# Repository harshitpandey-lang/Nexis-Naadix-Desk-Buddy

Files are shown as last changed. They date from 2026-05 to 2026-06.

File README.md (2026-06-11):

# Nexis
model_nexis_2026-Jun-03_01-21-36AM-000_CustomizedView11682904690_png

Nexis is a dual AI powered desk automation bot which uses raspberry pi to run a local llm and also uses a cloud deployed ai agent to do the tasks given to it in small chunks. We can give instructions through the interactive touch screen and also through the micophone. 
It uses esp32 to give commands to the device connected through the USB. 

## Overview

Nexis is a desk buddy which can do all sort of works upon good training and customisation. It uses a raspberry pi and open source AI model to break works into smaller steps. It uses the the local llm to generte the HID code respective to every step given uses python to asses if the work is performed then goes ahed with next step till all are completed. 
It uses esp32 to give HID code to the PC connected to make it do or perform a particular task. It can communicate or given instructionthrough the Touchscreen and Microphone.

---

## System Architecture
User

 │
 
 ├── Voice Input
 
 ├── Touchscreen Input
 
 │
 
 ▼
 
Raspberry Pi 4

 │
 
 ├── Local LLM
 
 ├── Task Planner
 
 ├── Verification Engine
 
 └── Cloud AI Agent
 
 │
 
 ▼
 
ESP32-S3 HID Controller

 │
 
 ▼
 
Connected Computer

 │
 
 ├── Keyboard Events
 
 ├── Mouse Events
 
 └── Workflow Execution

## Specifications

| Parameters | Value |
| Code | Python|
| Hardware | Raspberry pi model B |
| Design | 3d printed and rubber keys|

### Hardware

| Component | Purpose |
|---|---|
| Raspberry Pi 4 Model B | Main computing unit |
| Official Raspberry Pi Display | User interface |
| ESP32-S3 | HID controller |
| INMP441 Microphone | Voice input |
| MAX98357A Amplifier | Audio output |
| Speaker | Voice feedback |
| Rotary Encoder | Navigation control |
| Push Buttons | User interaction |
| LiPo Battery | Portable power |

{549CDC2C-EC70-4538-B992-6CFFC3E95AC3}
nexus deskbuddy

See BOM.md for the complete bill of materials.

---

## Software

- Backend Language
  - Python
- Framework
  - FastAPI
- AI
  - OpenAI API
  - Claude API
  - Gemini API
- Data Models
  - Pydantic
- Hosting
  - Render

### Raspberry Pi

Install:

* Raspberry Pi OS
* Python
* Git
* Required libraries

### ESP32

Install:

* Arduino IDE or PlatformIO
* ESP32 Board Package

---

### How It Works
- User gives an instruction.
- Nexis interprets the request.
- AI breaks the task into smaller steps.
- Local verification checks progress.
- ESP32 receives generated HID commands.
- Commands are executed on the connected computer.
- Nexis confirms completion and proceeds to the next step.

This process continues until the entire workflow is completed.

---

## Gallery

<p align="center">
  
  
  
</p>

<p align="center">
  
  
  
</p>

## Future Improvements

- It can work as full work automation
- It can also control the other tech stacks of your rooms
- If developed correctly it can do the job of any person

## Acknowledgement

- The raspberrry pi model 4 was alloted by my college (Jaypee Institute of Information Technology), which I am grateful.
- I am grateful for the oppurtunity presented by the Hack Club called fallout, Which I am a part of and am proud of making this project under their guidance for more reference realted to the fallout event (https://fallout.hackclub.com/path).
- I am also grateful for the help given by my seniors.

---
# Zine page
WhatsApp Image 2026-06-04 at 8 46 59 AM

---

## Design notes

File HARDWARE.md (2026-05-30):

# Hardware Documentation

## Overview

Nexis is a desktop companion designed around a Raspberry Pi and an ESP32-S3. The Raspberry Pi acts as the primary controller while the ESP32-S3 provides USB HID functionality for interacting with a computer.

The hardware was designed to provide:

* Voice input
* Audio output
* Touchscreen interaction
* Physical controls
* USB HID automation
* Portable power support

---

# System Architecture

```text
                 User
                   │
                   ▼
         Official Pi Display
                   │
                   ▼
             Raspberry Pi
        ┌──────────┼──────────┐
        │          │          │
        ▼          ▼          ▼
    Microphone  Speaker    ESP32-S3
        │                     │
        ▼                     ▼
    Voice Input         USB HID Output
                              │
                              ▼
                           Computer
```

---

# Main Controller

## Raspberry Pi

Role:

* System controller
* User interface
* Voice processing
* OAI communication
* Feedback monitoring

Connected Components:

* Display
* Microphone
* Amplifier
* ESP32 Interface
* Buttons
* Rotary Encoder

---

# HID Controller

## ESP32-S3

Role:

* Keyboard emulation
* Mouse emulation
* Command execution
* Secondary communication controller

Benefits:

* Native USB support
* WiFi support
* Low power consumption
* Reliable HID operation

---

# Display

## Official Raspberry Pi Touchscreen

Purpose:

* Device status
* User interaction
* Task approval
* Settings menu

Displayed Information:

* Network status
* Voice status
* Current task
* Approval prompts
* Error messages

---

# Audio Input

## INMP441 I2S Microphone

Purpose:

* Voice command capture

Interface:

* I2S

Connections:

```text
3V3
GND
WS
SCK
SD
```

Connected To:

* Raspberry Pi

---

# Audio Output

## MAX98357A Amplifier

Purpose:

* Audio playback
* Voice feedback

Interface:

* I2S

Connected To:

* Raspberry Pi

Output:

* 3W Speaker

---

# Rotary Encoder

Purpose:

* Navigation
* Volume control
* Menu selection

Signals:

```text
CLK
DT
SW
```

Connected To:

* Raspberry Pi GPIO

---

# Front Panel Buttons

Purpose:

* Manual control
* Emergency stop
* Menu navigation

Functions:

* Confirm
* Cancel
* Back
* Wake Device

---

# Power System

## USB-C Input

Primary power source.

Provides:

* Raspberry Pi power
* Peripheral power
* Charging input

---

## Battery Support

Optional portable operation.

Supports:

* Single-cell LiPo battery

Functions:

* Backup power
* Portable usage

---

# Speaker

Purpose:

* Audio feedback
* Notifications
* Voice responses

Connected Through:

```text
MAX98357A
        ↓
      Speaker
```

---

# Internal Communication

## Raspberry Pi ↔ ESP32-S3

Purpose:

* Command transfer
* Status reporting

Possible Interfaces:

* UART
* MQTT over WiFi
* USB Serial

Current Design:

* MQTT communication

---

# Hardware Features

### Input

* Touchscreen
* Microphone
* Buttons
* Rotary Encoder

### Output

* Speaker
* Display
* HID Keyboard
* HID Mouse

### Connectivity

* WiFi
* USB

### Power

* USB-C
* Battery Backup

---

# Design Goals

1. Simple architecture

2. Reliable HID operation

3. Easy assembly

4. Expandable design

5. Portable operation

6. Educational value

7. Hack Club Fallout compatibility

---

# Revision

Current Revision: V1

Status:

* Schematic Complete
* PCB In Development
* Firmware In Development
* Assembly Pending

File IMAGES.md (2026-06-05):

# 📸 Nexis Project Gallery

<table>
<tr>
<td width="50%">

</td>

<td width="50%">

</td>
</tr>
</table>

---

<table>
<tr>
<td width="33%">

</td>

<td width="33%">

</td>

<td width="33%">

</td>
</tr>

<tr>
<td width="33%">

</td>

<td width="33%">

</td>

<td width="33%">

</td>
</tr>
</table>

---

## 🛠️ Design Process

<table>
<tr>
<td></td>
<td></td>
<td></td>
</tr>

<tr>
<td></td>
<td></td>
<td></td>
</tr>

<tr>
<td></td>
<td></td>
<td></td>
</tr>

<tr>
<td></td>
<td></td>
<td></td>
</tr>

<tr>
<td></td>
<td></td>
<td></td>
</tr>

<tr>
<td></td>
<td></td>
<td></td>
</tr>

<tr>
<td></td>
<td></td>
<td></td>
</tr>

<tr>
<td></td>
<td></td>
<td></td>
</tr>

<tr>
<td colspan="3">

</td>
</tr>
</table>

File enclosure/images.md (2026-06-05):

## Interactive CAD Models

<p align="center">
  <a href="https://autode.sk/49pJZgw">
    
  </a>

  <a href="https://autode.sk/3PAl5UJ">
    
  </a>
</p>

---

## Final Design Renders

<p align="center">
  
  
  
</p>

<p align="center">
  
  
</p>

---

## Design & Development Process

<p align="center">
  
  
  
</p>

<p align="center">
  
  
  
</p>

<p align="center">
  
  
  
</p>

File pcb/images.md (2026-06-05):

## 🚀 Interactive CAD Models

<p align="center">
  <a href="https://autode.sk/49pJZgw">
    
  </a>

  <a href="https://autode.sk/3PAl5UJ">
    
  </a>
</p>

<p align="center">
  <a href="https://autode.sk/49pJZgw">
    
  </a>
</p>

<p align="center">
Click the preview above to explore the interactive Fusion 360 model.
</p>

---

## 📸 CAD Design Gallery

<table>
<tr>
<td></td>
<td></td>
</tr>

<tr>
<td></td>
<td></td>
</tr>

<tr>
<td></td>
<td></td>
</tr>

<tr>
<td></td>
<td></td>
</tr>

<tr>
<td></td>
<td></td>
</tr>
</table>
 src="https://github.com/user-attachments/assets/829b629e-79f1-4ea2-8aa1-b12885084f9d" />
Screenshot (43)

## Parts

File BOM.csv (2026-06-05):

Item | Category | Qty | Unit Price (INR) | Total (INR) | Supplier | Product Link | Purpose | Notes
Raspberry Pi 4 Model B (4GB) | Compute | 1 | 11299 | 11299 | Robu | https://robu.in/product/raspberry-pi-4-model-b-with-4-gb-ram/ | Main Controller | Runs UI voice processing and OAI communication
Seeed Studio 7 inch Capacitive Touchscreen | Display | 1 | 10139 | 10139 | Robu | https://robu.in/product/seeed-studio-7-inch-1024x600-capacitive-touchscreen/ | Primary User Interface | 1024x600 touchscreen display
ESP32-S3 N16R8 Development Board | Microcontroller | 1 | 540 | 540 | Robu | https://robu.in/product/esp32-s3-development-board-with-s3-n16r8/ | USB HID Controller | Keyboard and mouse emulation
GY-SPH0645LM4H I2S MEMS Microphone | Audio Input | 1 | 489 | 489 | Robu | https://robu.in/product/gy-sph0645lm4h-i2s-digital-audio-interfaces-mems-microphone-sensor/ | Voice Capture | I2S digital microphone
Adafruit MAX98357A I2S Amplifier | Audio Output | 1 | 730 | 730 | Robu | https://robu.in/product/adafruit-max98357a-i2s-3w-class-d-amplifier-breakout-board/ | Speaker Amplifier | Digital audio amplifier
Electronic Spices 2in 4Ω 5W Speaker | Audio Output | 1 | 143 | 143 | Amazon | https://www.amazon.in/Electronic-Spices-Power-Woofer-Speaker/dp/B0BN44HPF9/ | Voice Feedback | Main speaker
KY-040 Rotary Encoder Module | Input | 1 | 107 | 107 | Amazon | https://www.amazon.in/Electronic-Spices-KY-040-encoder-development/dp/B0BHWCWJDR/ | Navigation Control | Menu and volume navigation
Tactile Push Buttons | Input | 3 | 19 | 57 | Amazon | https://www.amazon.in/Tactile-momentry-button-Switch-Button/dp/B07NCZJX3M/ | User Controls | Confirm cancel shortcut buttons
Samsung INR50S 5000mAh Battery | Power | 1 | 649 | 649 | Robu | https://robu.in/product/samsung-3-7v-5000mah-drone-battery-pack/ | Portable Power | Optional battery backup
2 Pin Male Female Wire Connector Set | Power | 1 | 88 | 88 | Amazon | https://www.amazon.in/Female-2-5mm-Cable-Connector-Silicone/dp/B0837W4DC8/ | Battery and Internal Wiring Connector | Pre-wired male and female connectors for battery and module connections
USB-C Connector Module | Power | 1 | 50 | 50 | Generic | Local Supplier | Power Input | USB-C charging and power
Fan Header 2 Pin | Expansion | 1 | 15 | 15 | Generic | Local Supplier | Cooling Expansion | Future cooling support
2.54mm Pin Headers | Connectors | 2 | 20 | 40 | Generic | Local Supplier | Interconnects | GPIO breakout connections
PCB Fabrication (2 Layer) | PCB | 1 | 1200 | 1200 | JLCPCB | https://jlcpcb.com/ | Custom PCB | Main Nexis PCB
PCB Assembly Components Set | PCB | 1 | 500 | 500 | Mouser/DigiKey | Various | Passives | Resistors capacitors LEDs connectors
M2.5 Standoffs and Screws | Mechanical | 1 | 200 | 200 | Amazon | Various | Assembly | PCB and display mounting
Internal Wiring Set | Mechanical | 1 | 250 | 250 | Amazon | Various | Wiring | Jumper wires JST cables
3D Printed Enclosure | Mechanical | 1 | 1500 | 1500 | Self Manufactured | N/A | Enclosure | Fusion 360 custom design
USB-C Cable | Accessory | 1 | 150 | 150 | Amazon | Various | Power and Debugging | Development and deployment
Miscellaneous Hardware | Mechanical | 1 | 300 | 300 | Various | Various | Assembly | Adhesive spacers nuts inserts

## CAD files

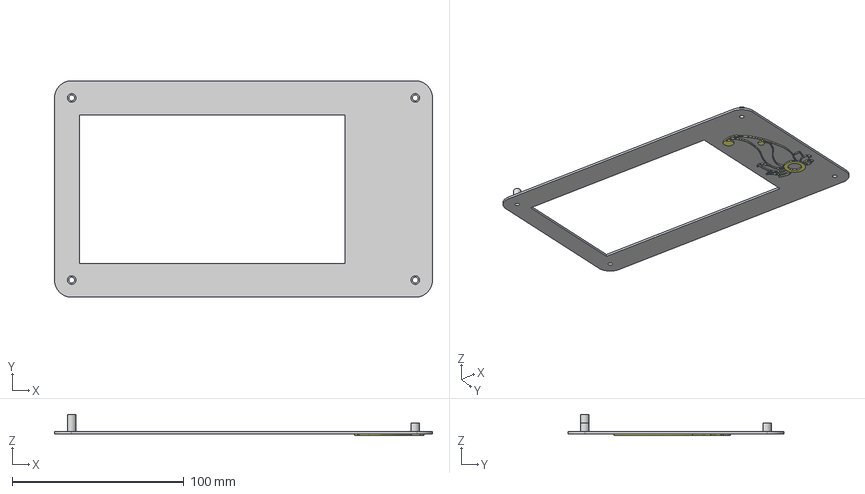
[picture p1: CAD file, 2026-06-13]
enclosure/Nexus desk front.step
220.0 x 126.0 x 12.5 mm

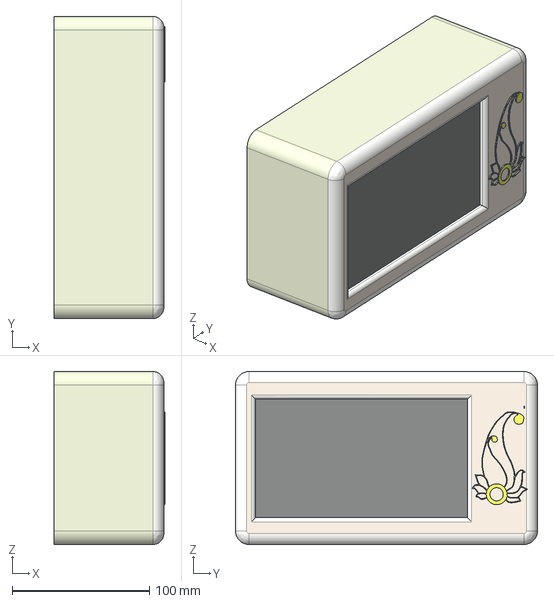
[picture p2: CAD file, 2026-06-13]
enclosure/model nexis.step
80.8 x 220.0 x 126.0 mm

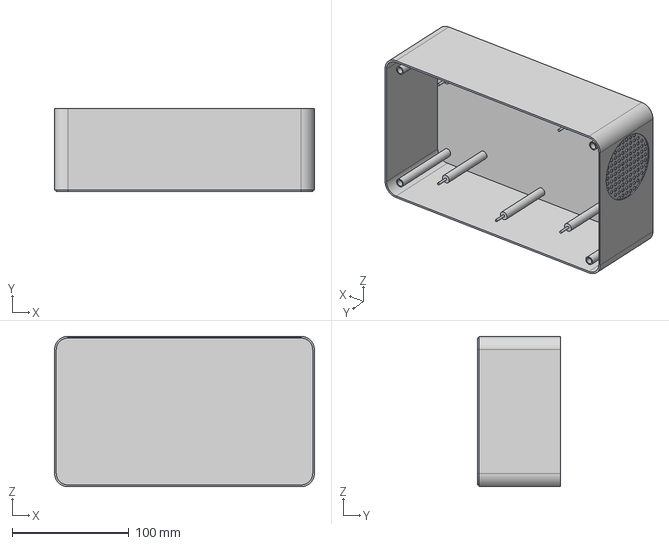
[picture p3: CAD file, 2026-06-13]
enclosure/nexus back.step
223.0 x 71.5 x 129.0 mm

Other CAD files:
enclosure/Nexus desk front.3mf
enclosure/Nexus desk front.f3d
enclosure/model nexis.3mf
enclosure/model nexis.f3z
enclosure/nexus back.f3d

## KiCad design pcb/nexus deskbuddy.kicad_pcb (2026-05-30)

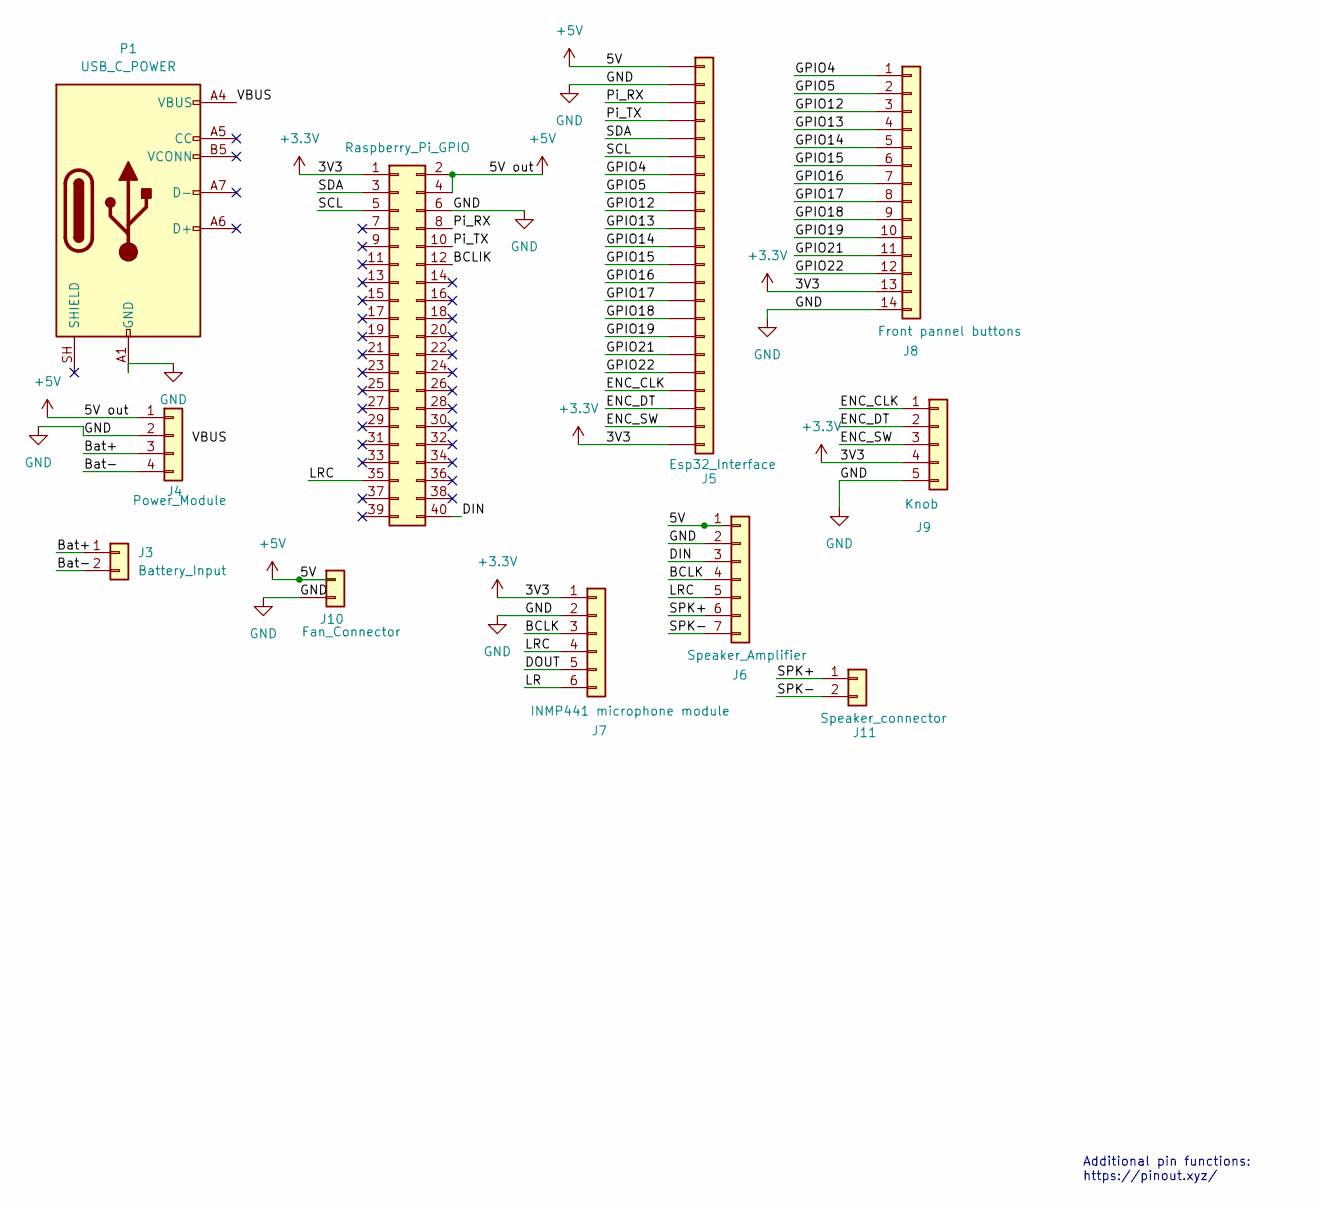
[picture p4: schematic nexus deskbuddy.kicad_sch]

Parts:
J2: Raspberry_Pi_GPIO; PinHeader_2x20_P2.54mm_Horizontal
J3: Battery_Input; JST_PH_B2B-PH-K_1x02_P2.00mm_Vertical
J4: Power_Module; FanPinHeader_1x04_P2.54mm_Vertical
J5: Esp32_Interface; PinHeader_1x22_P2.54mm_Horizontal
J6: Speaker_Amplifier; PinHeader_1x07_P2.54mm_Vertical
J7: INMP441 microphone module; PinHeader_1x06_P2.54mm_Vertical
J8: Front pannel buttons; PinHeader_1x14_P2.54mm_Horizontal
J9: Knob; PinHeader_1x05_P2.54mm_Horizontal
J10: Fan_Connector; PinHeader_1x02_P2.54mm_Horizontal
J11: Speaker_connector; PinHeader_1x02_P1.00mm_Horizontal
P1: USB_C_POWER; USB_C_Receptacle_Amphenol_124019772112A

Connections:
+3.3V: J2.1, J5.22, J7.1, J8.13, J9.4
+5V: J2.2, J2.4, J4.1, J5.1, J6.1, J10.1
/BCLIK: J2.12
/BCLK: J6.4, J7.3
/Bat+: J3.1, J4.3
/Bat-: J3.2, J4.4
/DIN: J2.40, J6.3
/DOUT: J7.5
/ENC_CLK: J5.19, J9.1
/ENC_DT: J5.20, J9.2
/ENC_SW: J5.21, J9.3
/GPIO4: J5.7, J8.1
/GPIO5: J5.8, J8.2
/GPIO12: J5.9, J8.3
/GPIO13: J5.10, J8.4
/GPIO14: J5.11, J8.5
/GPIO15: J5.12, J8.6
/GPIO16: J5.13, J8.7
/GPIO17: J5.14, J8.8
/GPIO18: J5.15, J8.9
/GPIO19: J5.16, J8.10
/GPIO21: J5.17, J8.11
/GPIO22: J5.18, J8.12
/LR: J7.6
/LRC: J2.35, J6.5, J7.4
/Pi_RX: J2.8, J5.3
/Pi_TX: J2.10, J5.4
/SCL: J2.5, J5.6
/SDA: J2.3, J5.5
/SPK+: J6.6, J11.1
/SPK-: J6.7, J11.2
/VBUS: P1.A4 (VBUS), P1.A9 (VBUS), P1.B4 (VBUS), P1.B9 (VBUS)
GND: J2.6, J4.2, J5.2, J6.2, J7.2, J8.14, J9.5, J10.2, P1.A1 (GND), P1.A12 (GND), P1.B1 (GND), P1.B12 (GND)

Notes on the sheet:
Additional pin functions: https://pinout.xyz/

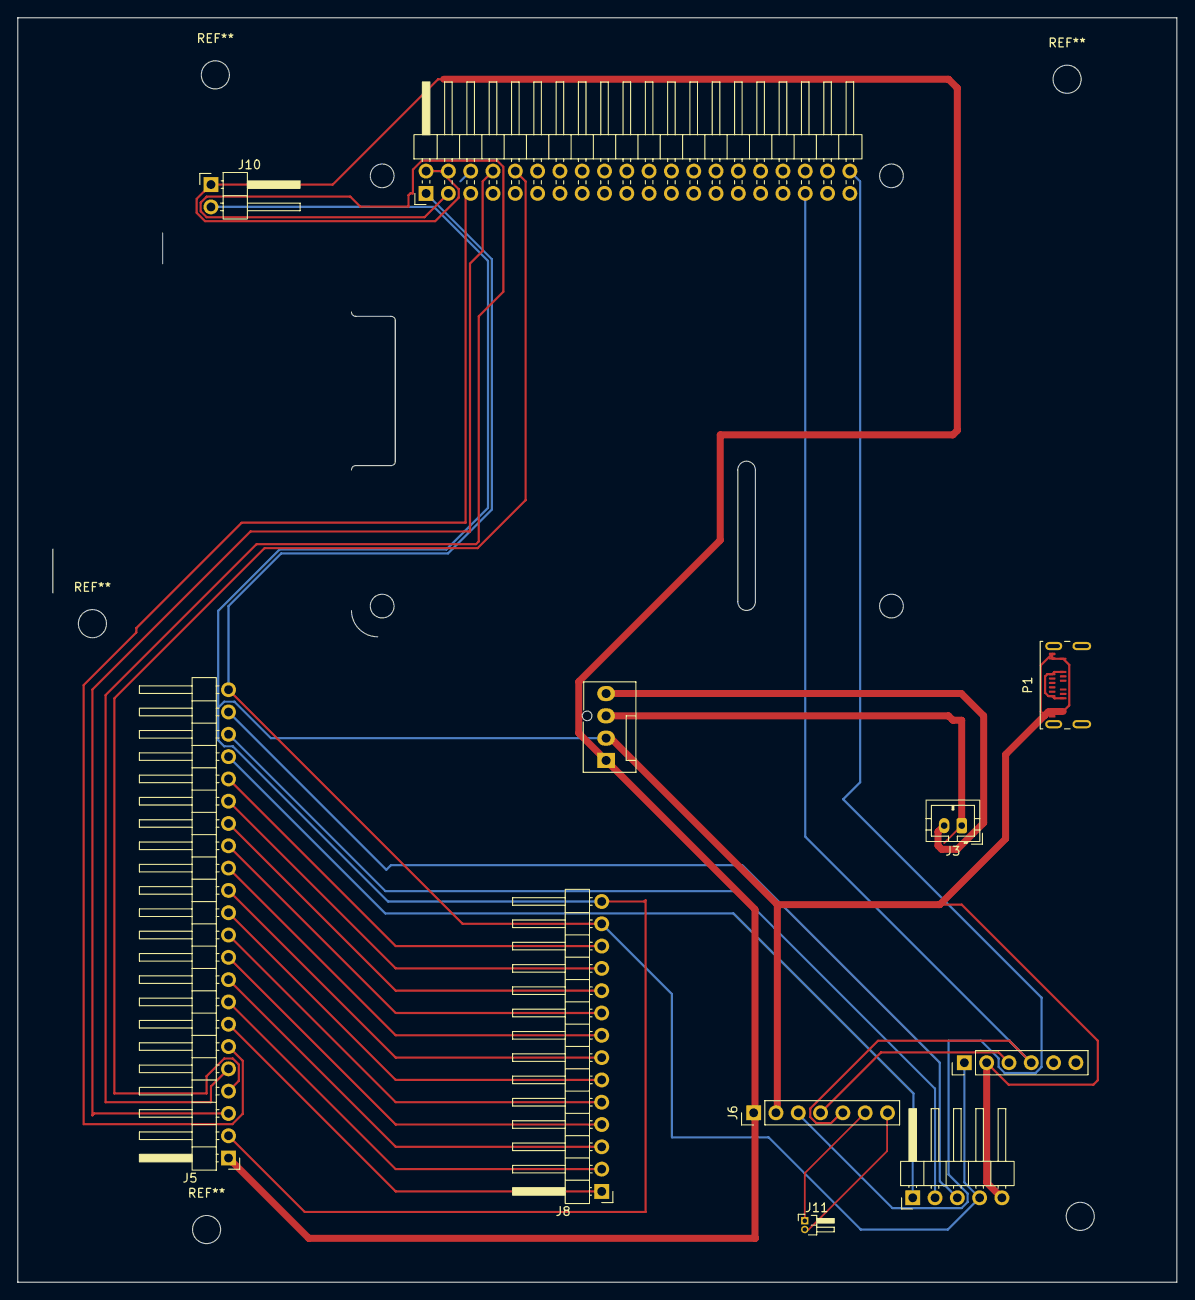
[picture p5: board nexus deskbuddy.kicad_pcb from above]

Board: 2 copper layers, 132.0 x 144.0 mm, 15 parts (0 on the bottom side), 30 nets.

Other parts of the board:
MH1, MH2, MH3, MH4: MountingHole_2.7mm_M2.5

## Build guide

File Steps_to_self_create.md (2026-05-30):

# Recreating Nexis

This section documents the process required to recreate the project from scratch.

## Requirements

### Hardware

* Raspberry Pi 4 Model B
* Official Raspberry Pi Display
* ESP32-S3
* INMP441 Microphone
* MAX98357A Amplifier
* Speaker
* Rotary Encoder
* Push Buttons
* LiPo Battery (Optional)

See BOM.md for the complete list.

---

## Software

### Raspberry Pi

Install:

* Raspberry Pi OS
* Python
* Git
* Required libraries

### ESP32

Install:

* Arduino IDE or PlatformIO
* ESP32 Board Package

---

# Step 1 — Clone Repositories

Clone:

```bash
git clone <oai-repository>
```

Clone:

```bash
git clone <nexis-repository>
```

---

# Step 2 — Prepare Raspberry Pi

Flash Raspberry Pi OS.

Connect:

* Display
* Keyboard
* Mouse

Perform:

```bash
sudo apt update
sudo apt upgrade
```

Install project dependencies.

---

# Step 3 — Configure OAI

Create environment file.

Add:

```text
API_KEY=
MQTT_SERVER=
```

Run test commands.

Verify OAI returns valid plans.

---

# Step 4 — Flash ESP32

Open:

```text
firmware/
```

Compile firmware.

Upload to ESP32-S3.

Verify:

* WiFi connection
* HID connection

---

# Step 5 — Manufacture PCB

Open:

```text
pcb/
```

Generate:

* Gerbers
* Drill Files
* BOM

Submit to PCB manufacturer.

---

# Step 6 — Assemble Hardware

Install:

* Raspberry Pi
* Display
* PCB
* Speaker
* Buttons
* Encoder

Complete wiring.

Verify power rails.

---

# Step 7 — System Test

Test:

### Audio

* Microphone
* Speaker

### Input

* Touchscreen
* Buttons
* Encoder

### Communication

* Pi ↔ ESP32

### HID

* Keyboard
* Mouse

---

# Step 8 — Final Validation

Test example commands:

```text
Open YouTube

Open Calculator

Search Google

Upload File
```

Verify:

* OAI response
* Approval screen
* HID execution

---

# Manufacturing Notes

The PCB included in this repository is an early revision.

Future revisions may change:

* Component placement
* Routing
* Connector locations

Always verify the latest schematic before ordering boards.

---

# Current Project State

Completed:

* OAI
* CAD Design
* PCB Design
* Documentation

In Progress:

* Firmware
* PCB Validation
* Physical Assembly

Planned:

* Manufacturing
* Testing
* Final Enclosure Revision

The repository represents the current development state and will continue evolving as physical prototypes are produced and tested.
